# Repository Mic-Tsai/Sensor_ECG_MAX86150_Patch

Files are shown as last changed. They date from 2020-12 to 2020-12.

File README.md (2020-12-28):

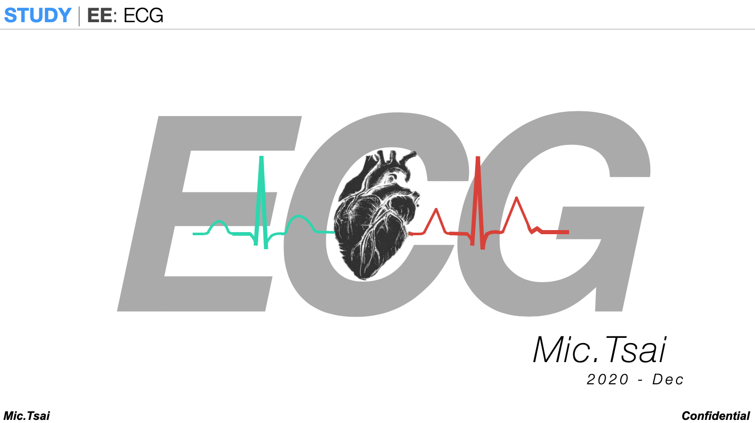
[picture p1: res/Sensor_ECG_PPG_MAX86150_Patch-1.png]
*Sensor_MAX86150*

# Sensor_ECG_PPG_MAX86150 | Patch



Arduino based sensor learning project. This project is further application from Health_Sensor_ecg_ppg_max86150 dev-board, plotting the ECG curve which used Processing on your computer.

 - Bias Cancellation | Store raw data in time, when new data coming that bias level will calculate as hysteresis filter.

 - Heart Rate Detect | Check windows will output the BPM results (ECG).

This board also support WiFi transmission via ESPNOW (ESP8266 Broadcast), and need power by battery. You need 2x esp8266 board.

1) Read receiver esp8266's mac address.
2) Fill it into the transmitter sketch. "ECG_ESP8266_MAX86150_V6"

** **A Known Issue** **

Sampling rate from MAX86150 set as 200sps, but ESP8266's multiplex with ESP-NOW and sensor hub reading task will low down the output sample rate to ~150sps. When you measuring your ECG in real-time plot may show the missing R-R interval. (R-peak missing!) Don't worry, it just the lower sample  caused.

```
Arduino tool kit, and require the following material:
- MCU: ESP8266 
- Sensor: MAX86150
```
##

For coding example, you need the following library:

* [protocentral_max86150_ecg_ppg](https://github.com/Protocentral/protocentral_max86150_ecg_ppg)

## 

Any question or need technical support:

* Contact me via mail (xbcke12345@gmail.com)

   

## 
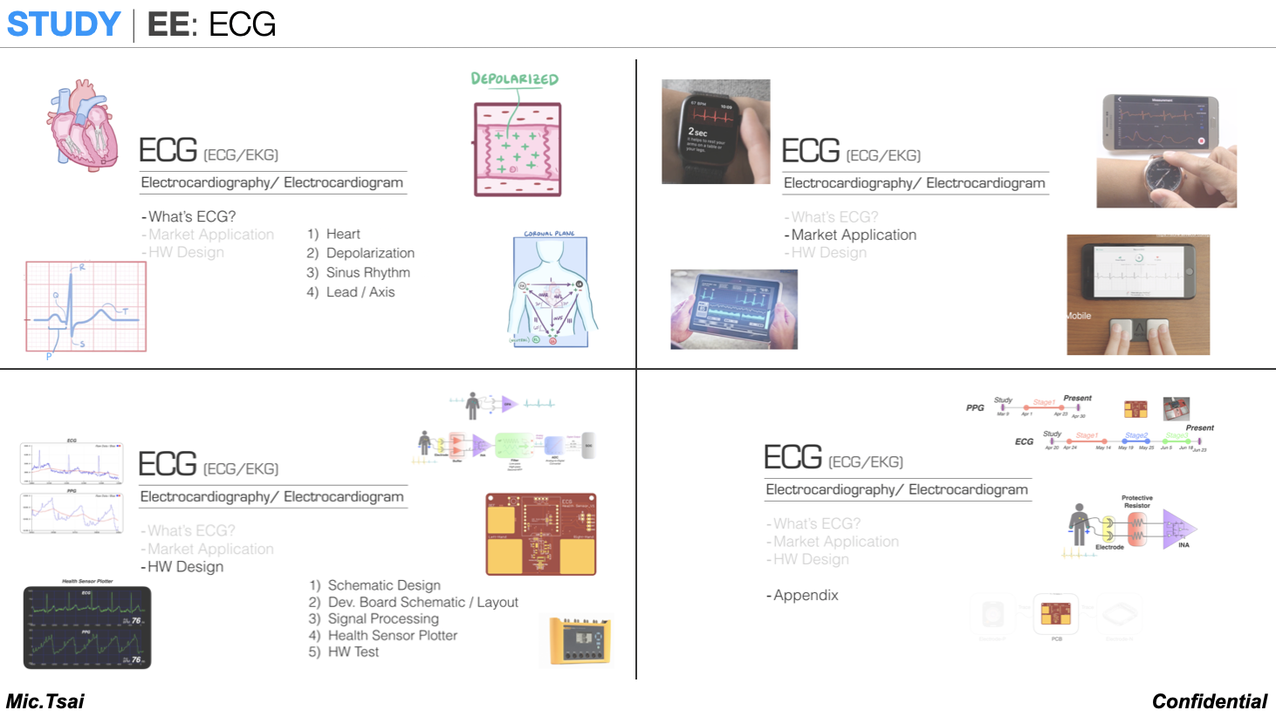
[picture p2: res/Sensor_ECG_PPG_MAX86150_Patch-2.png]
*Sensor_MAX86150*

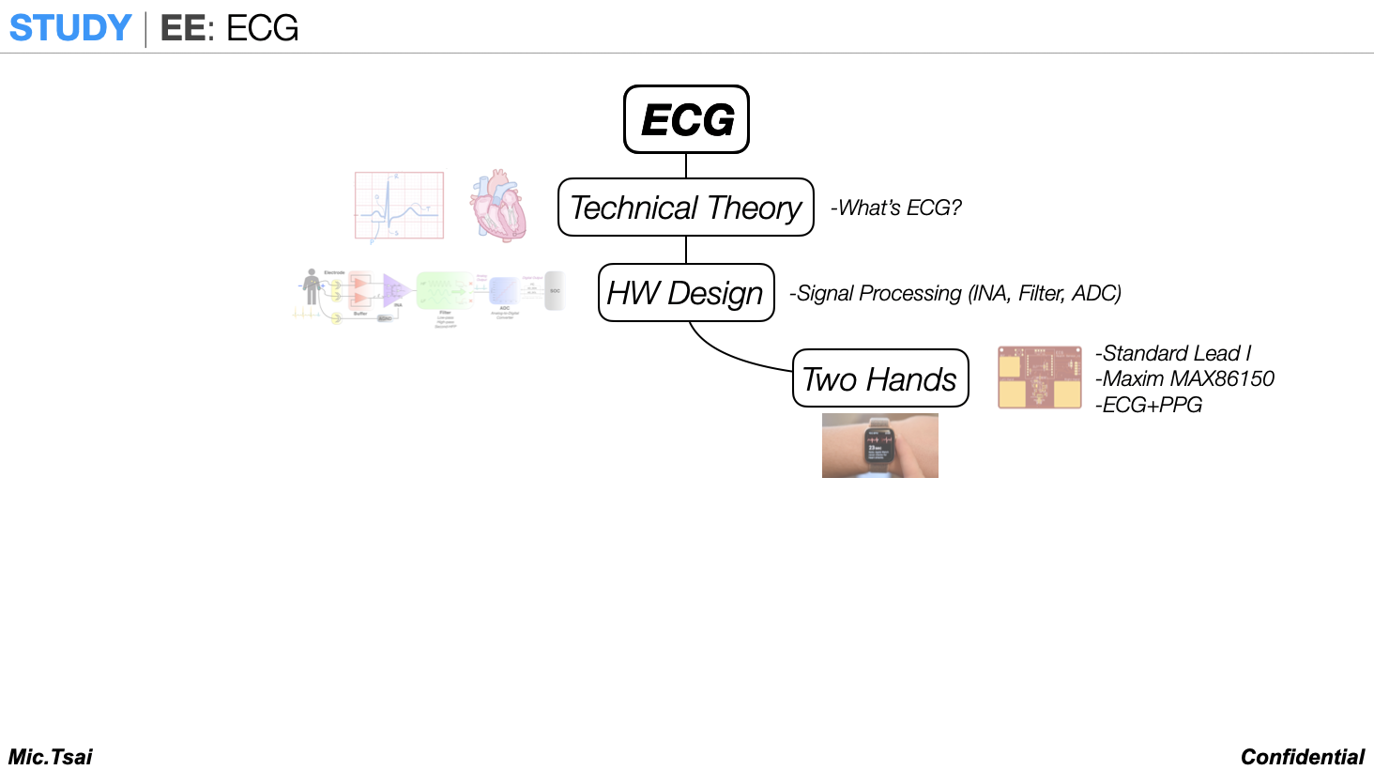
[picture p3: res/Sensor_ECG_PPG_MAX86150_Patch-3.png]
*Sensor_MAX86150*

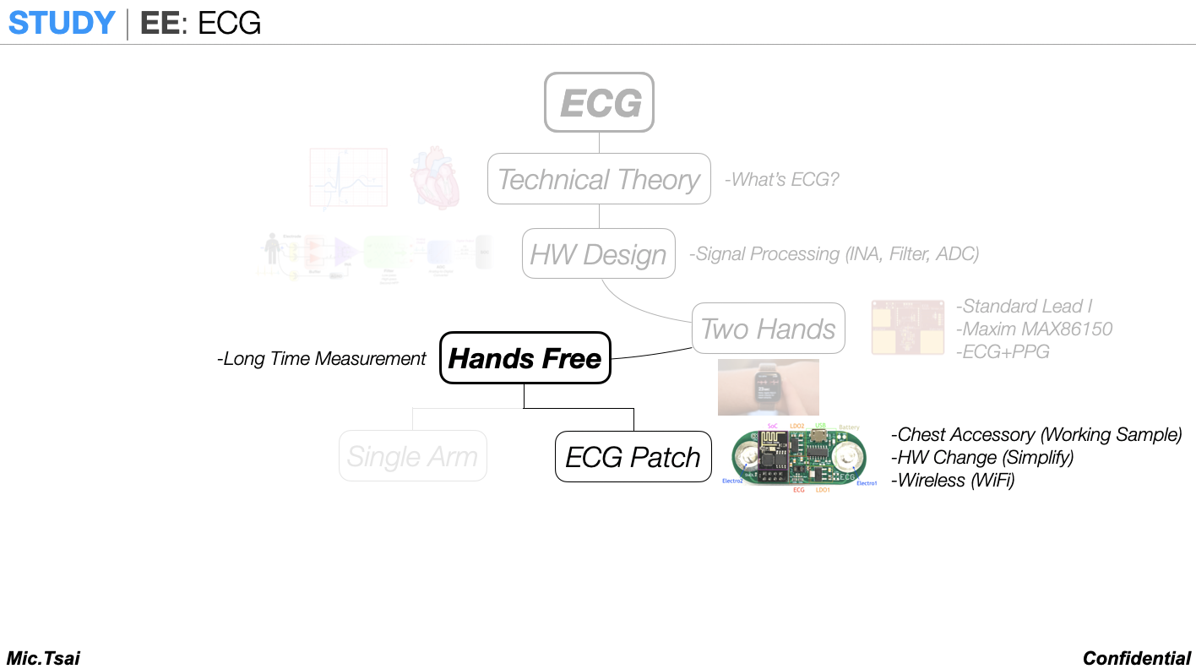
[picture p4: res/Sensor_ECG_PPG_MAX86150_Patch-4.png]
*Sensor_MAX86150*

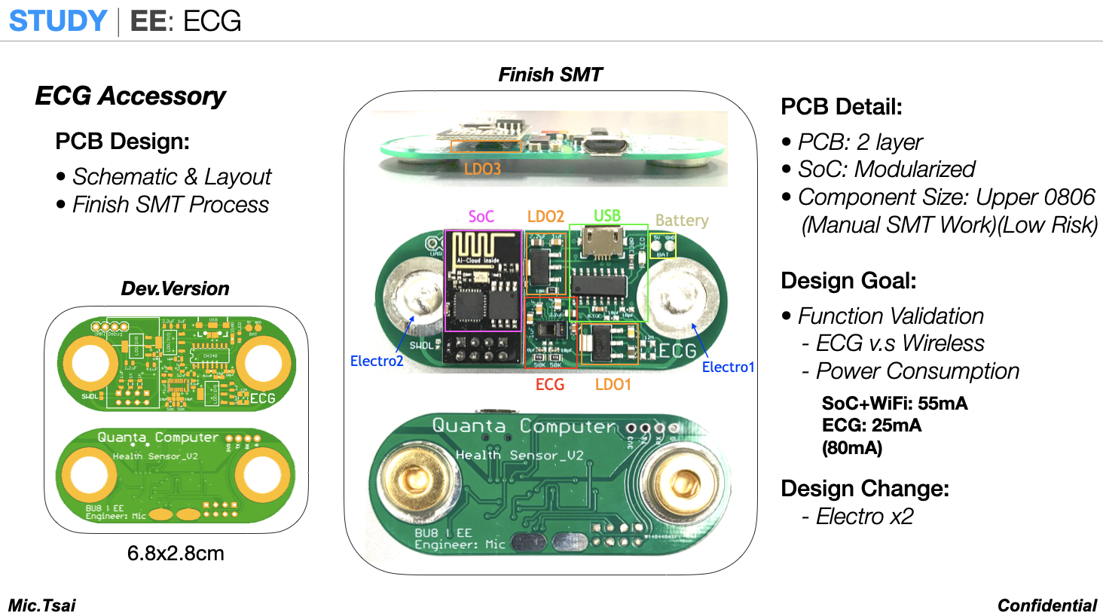
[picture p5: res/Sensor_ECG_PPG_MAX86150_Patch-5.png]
*Sensor_MAX86150*

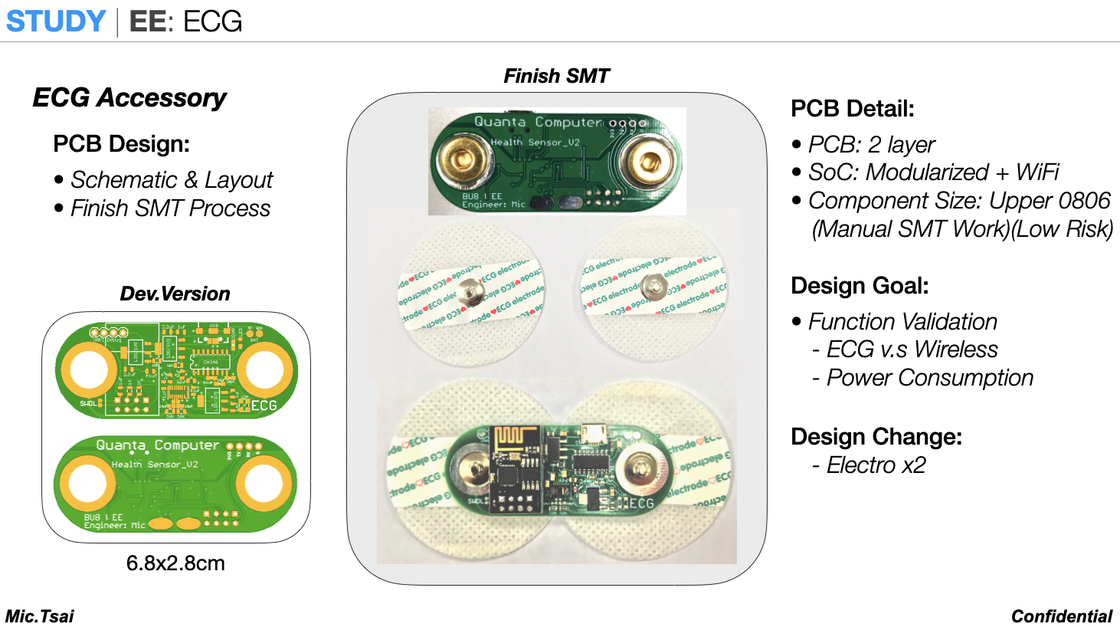
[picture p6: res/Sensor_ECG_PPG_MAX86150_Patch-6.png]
*Sensor_MAX86150*

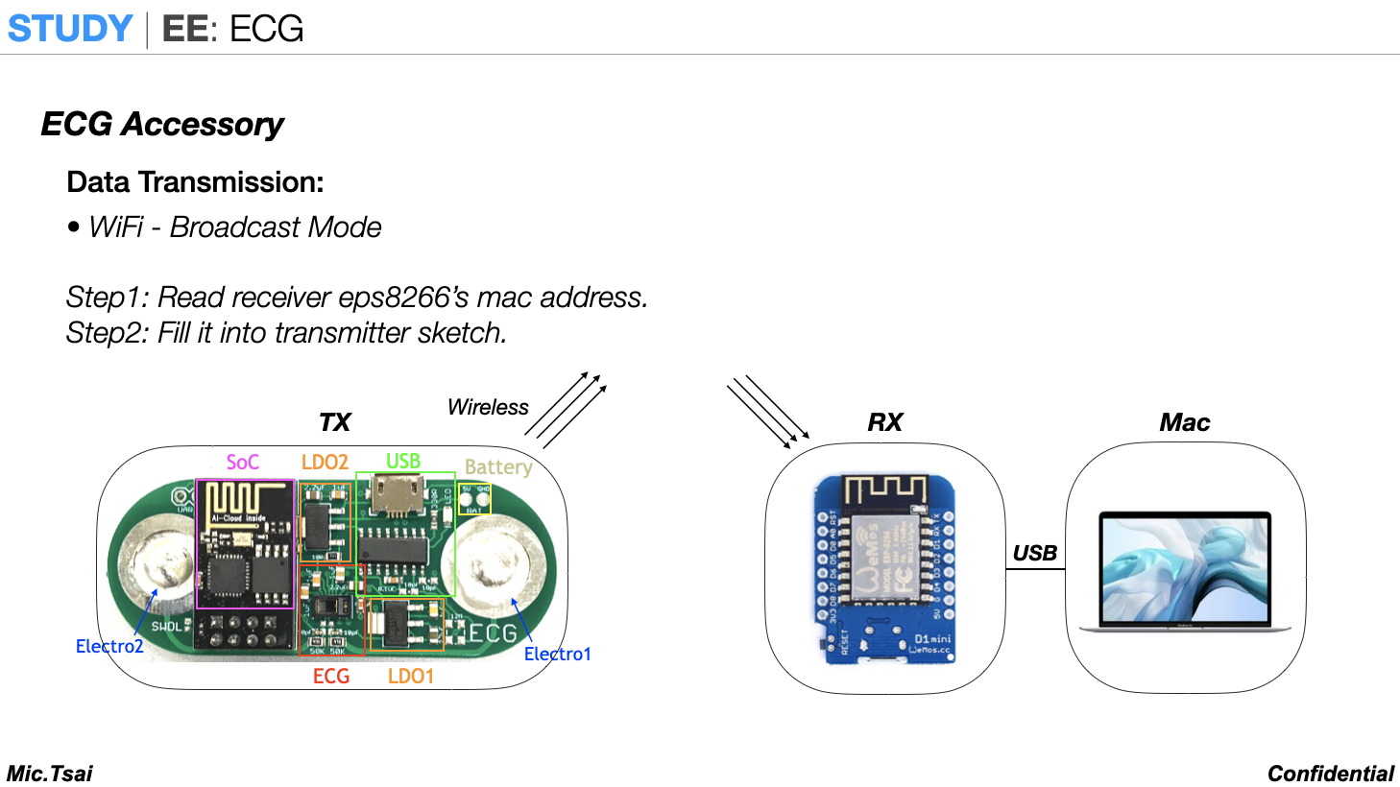
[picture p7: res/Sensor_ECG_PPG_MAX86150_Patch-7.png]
*Sensor_MAX86150*

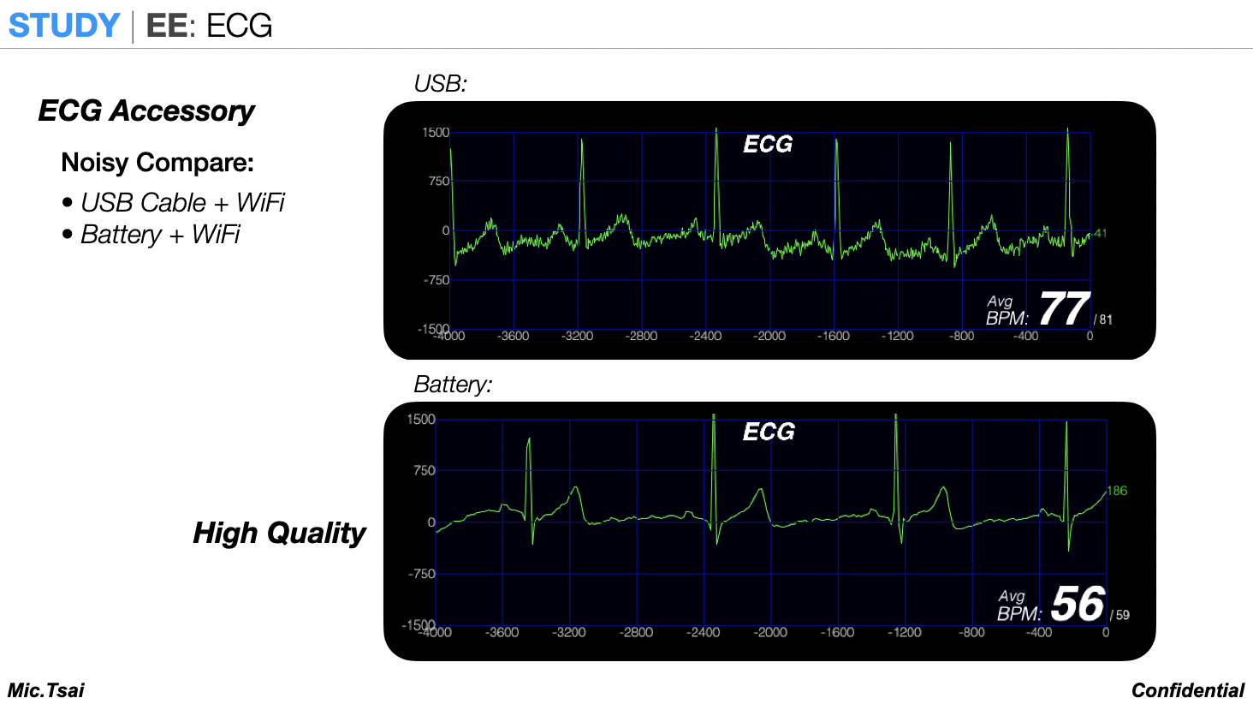
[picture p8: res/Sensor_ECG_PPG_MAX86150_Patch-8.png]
*Sensor_MAX86150*

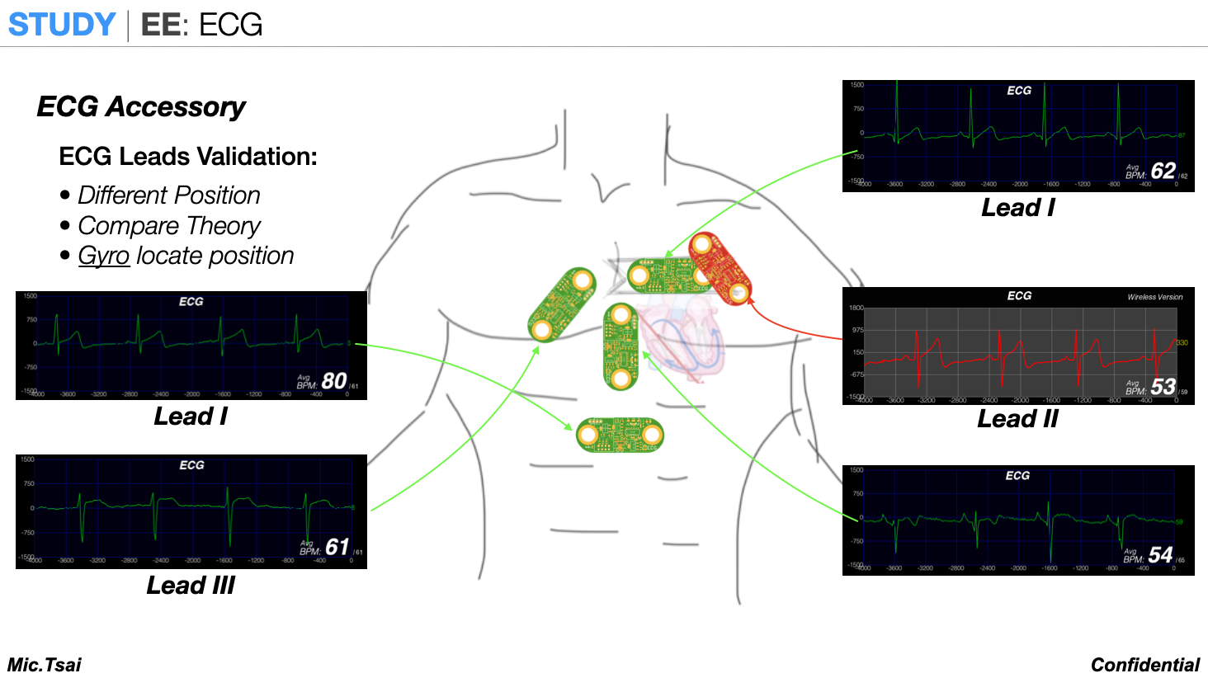
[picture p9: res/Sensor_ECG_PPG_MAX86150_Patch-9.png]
*Sensor_MAX86150*

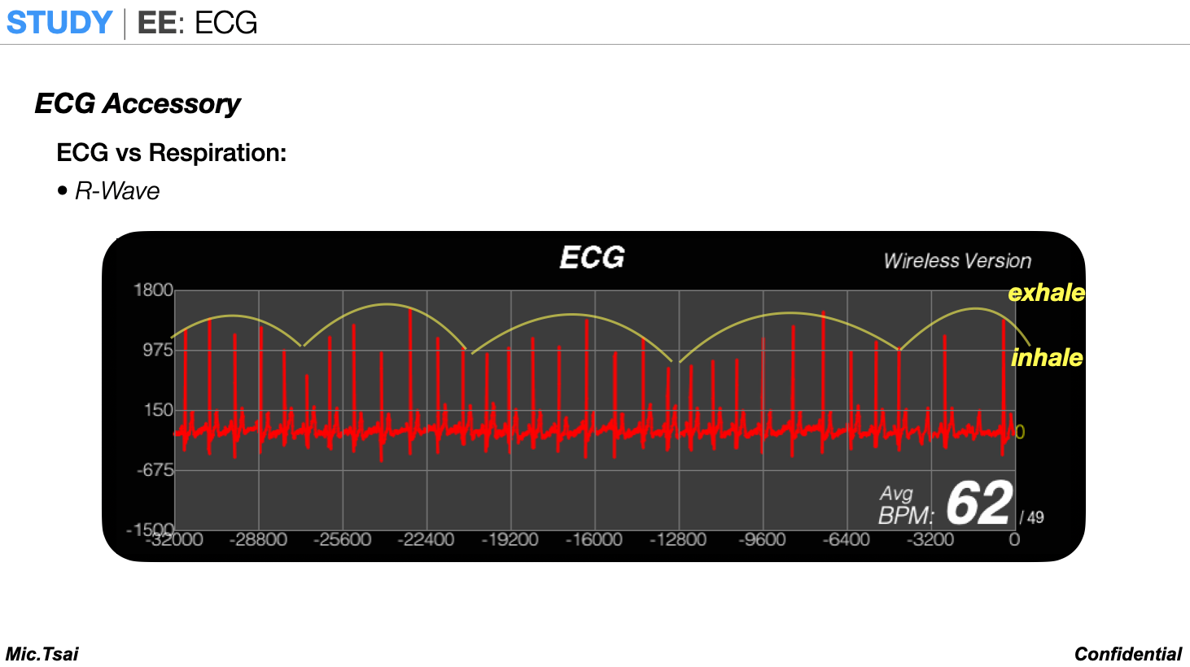
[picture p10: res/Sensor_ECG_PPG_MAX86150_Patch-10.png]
*Sensor_MAX86150*

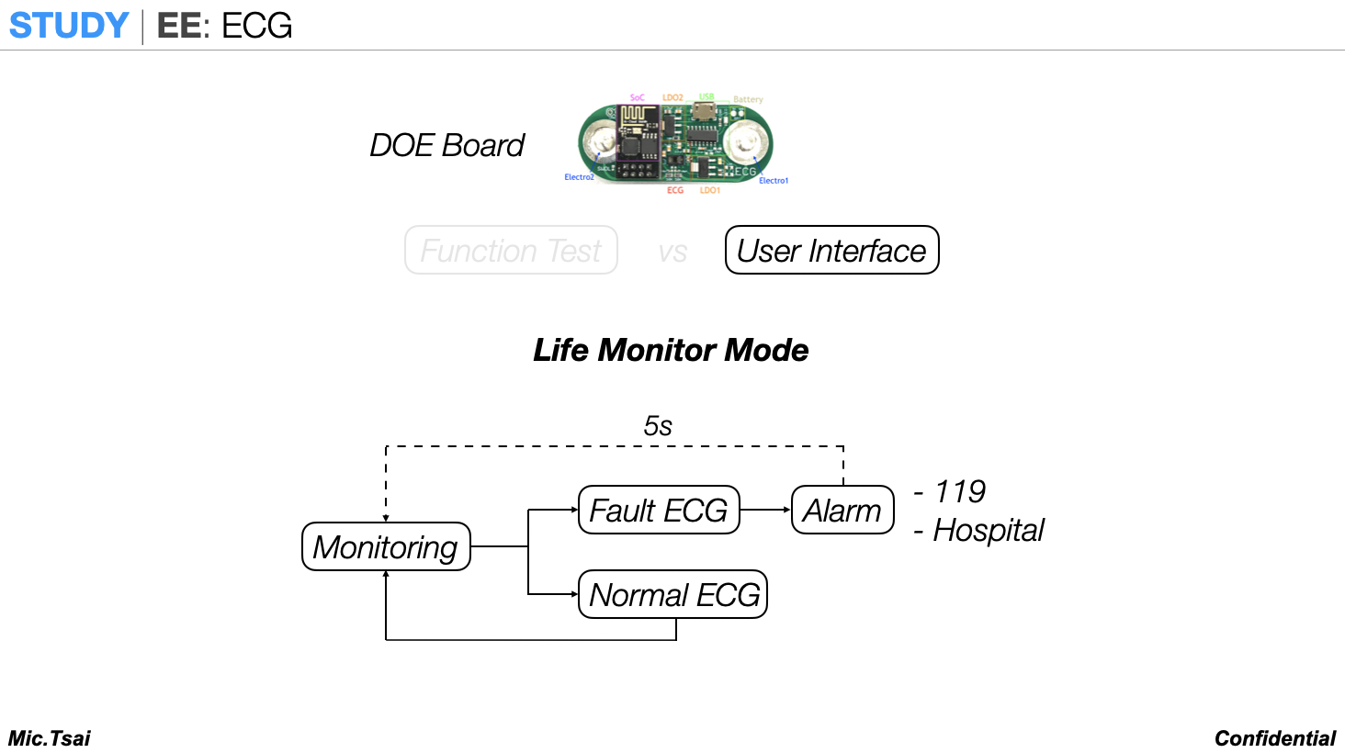
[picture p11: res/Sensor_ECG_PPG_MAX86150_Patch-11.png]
*Sensor_MAX86150*

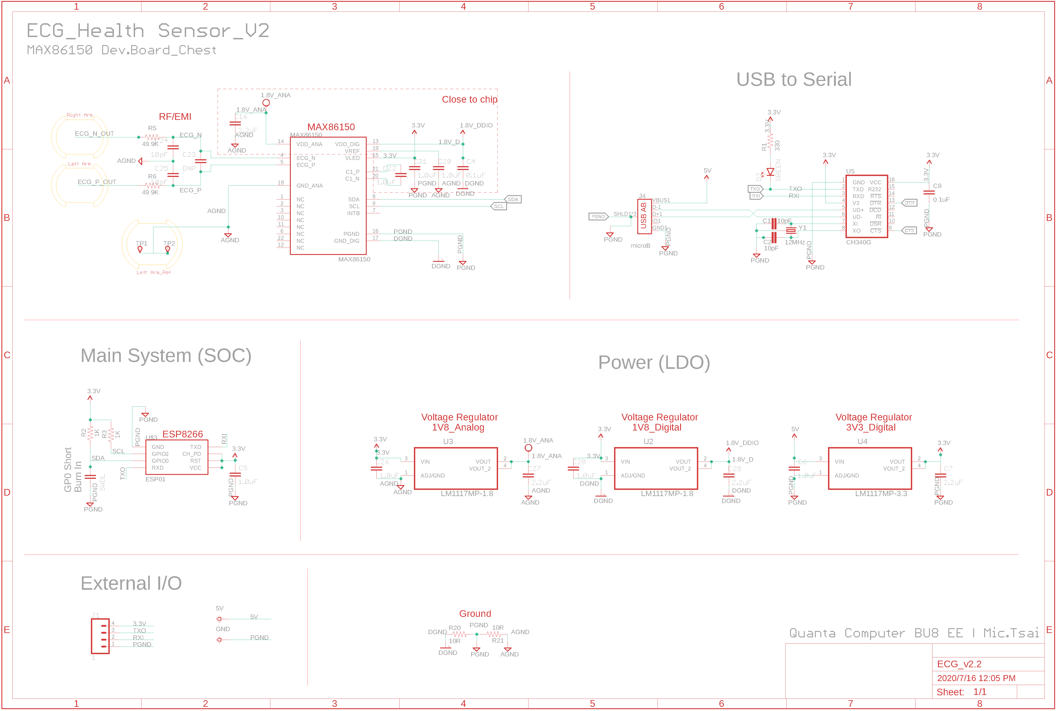
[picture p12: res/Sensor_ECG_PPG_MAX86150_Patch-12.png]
*Sensor_MAX86150*

## 

>### License Information
>>This product is open source! Both, our hardware and software are open source and licensed under the following:
>>#### Hardware
>>>All hardware is released under [Creative Commons Share-alike 4.0 International](http://creativecommons.org/licenses/by-sa/4.0/)
>>#### Software 
>>>All software is released under the MIT License [http://opensource.org/licenses/MIT](http://opensource.org/licenses/MIT)
>>#### Documentation
>>>The documentation on this page is released under [Creative Commons Share-alike 4.0 International](http://creativecommons.org/licenses/by-sa/4.0/)

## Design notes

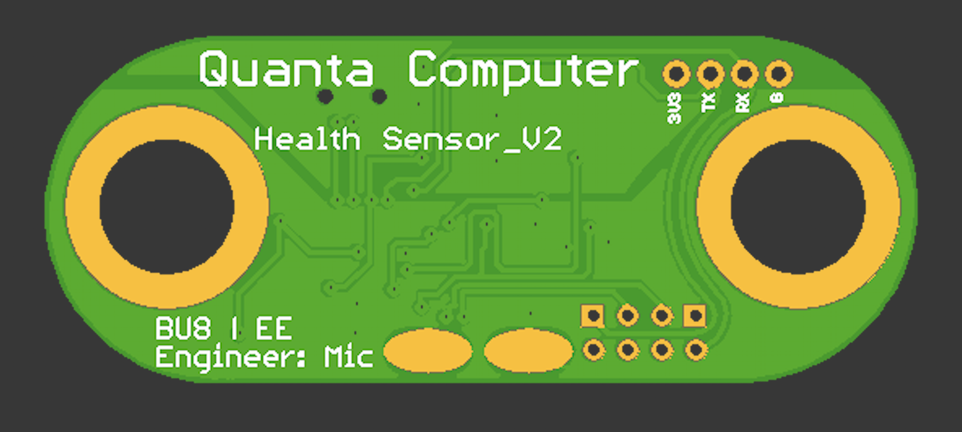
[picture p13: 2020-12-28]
hardware/ECG_max86150_patch_v2.2/ECG_max86150_patch_v2.2_B.png

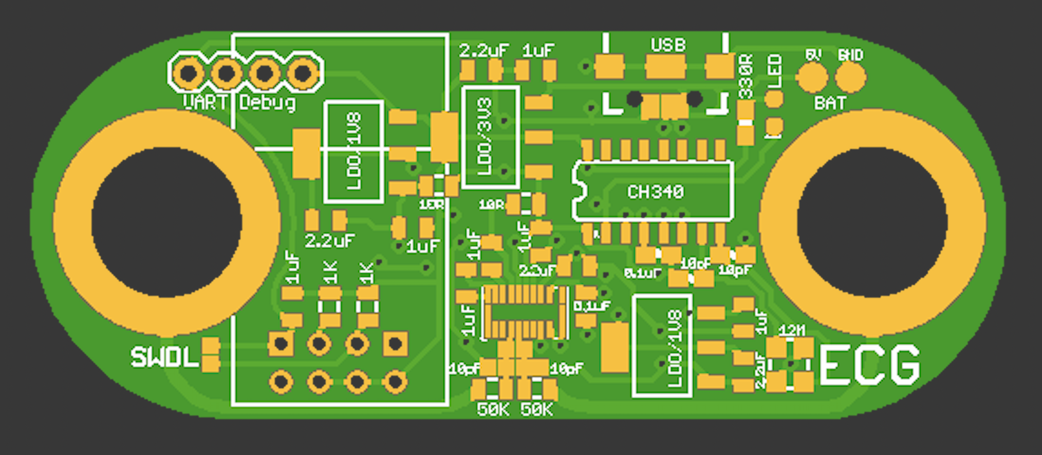
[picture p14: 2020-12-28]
hardware/ECG_max86150_patch_v2.2/ECG_max86150_patch_v2.2_T.png

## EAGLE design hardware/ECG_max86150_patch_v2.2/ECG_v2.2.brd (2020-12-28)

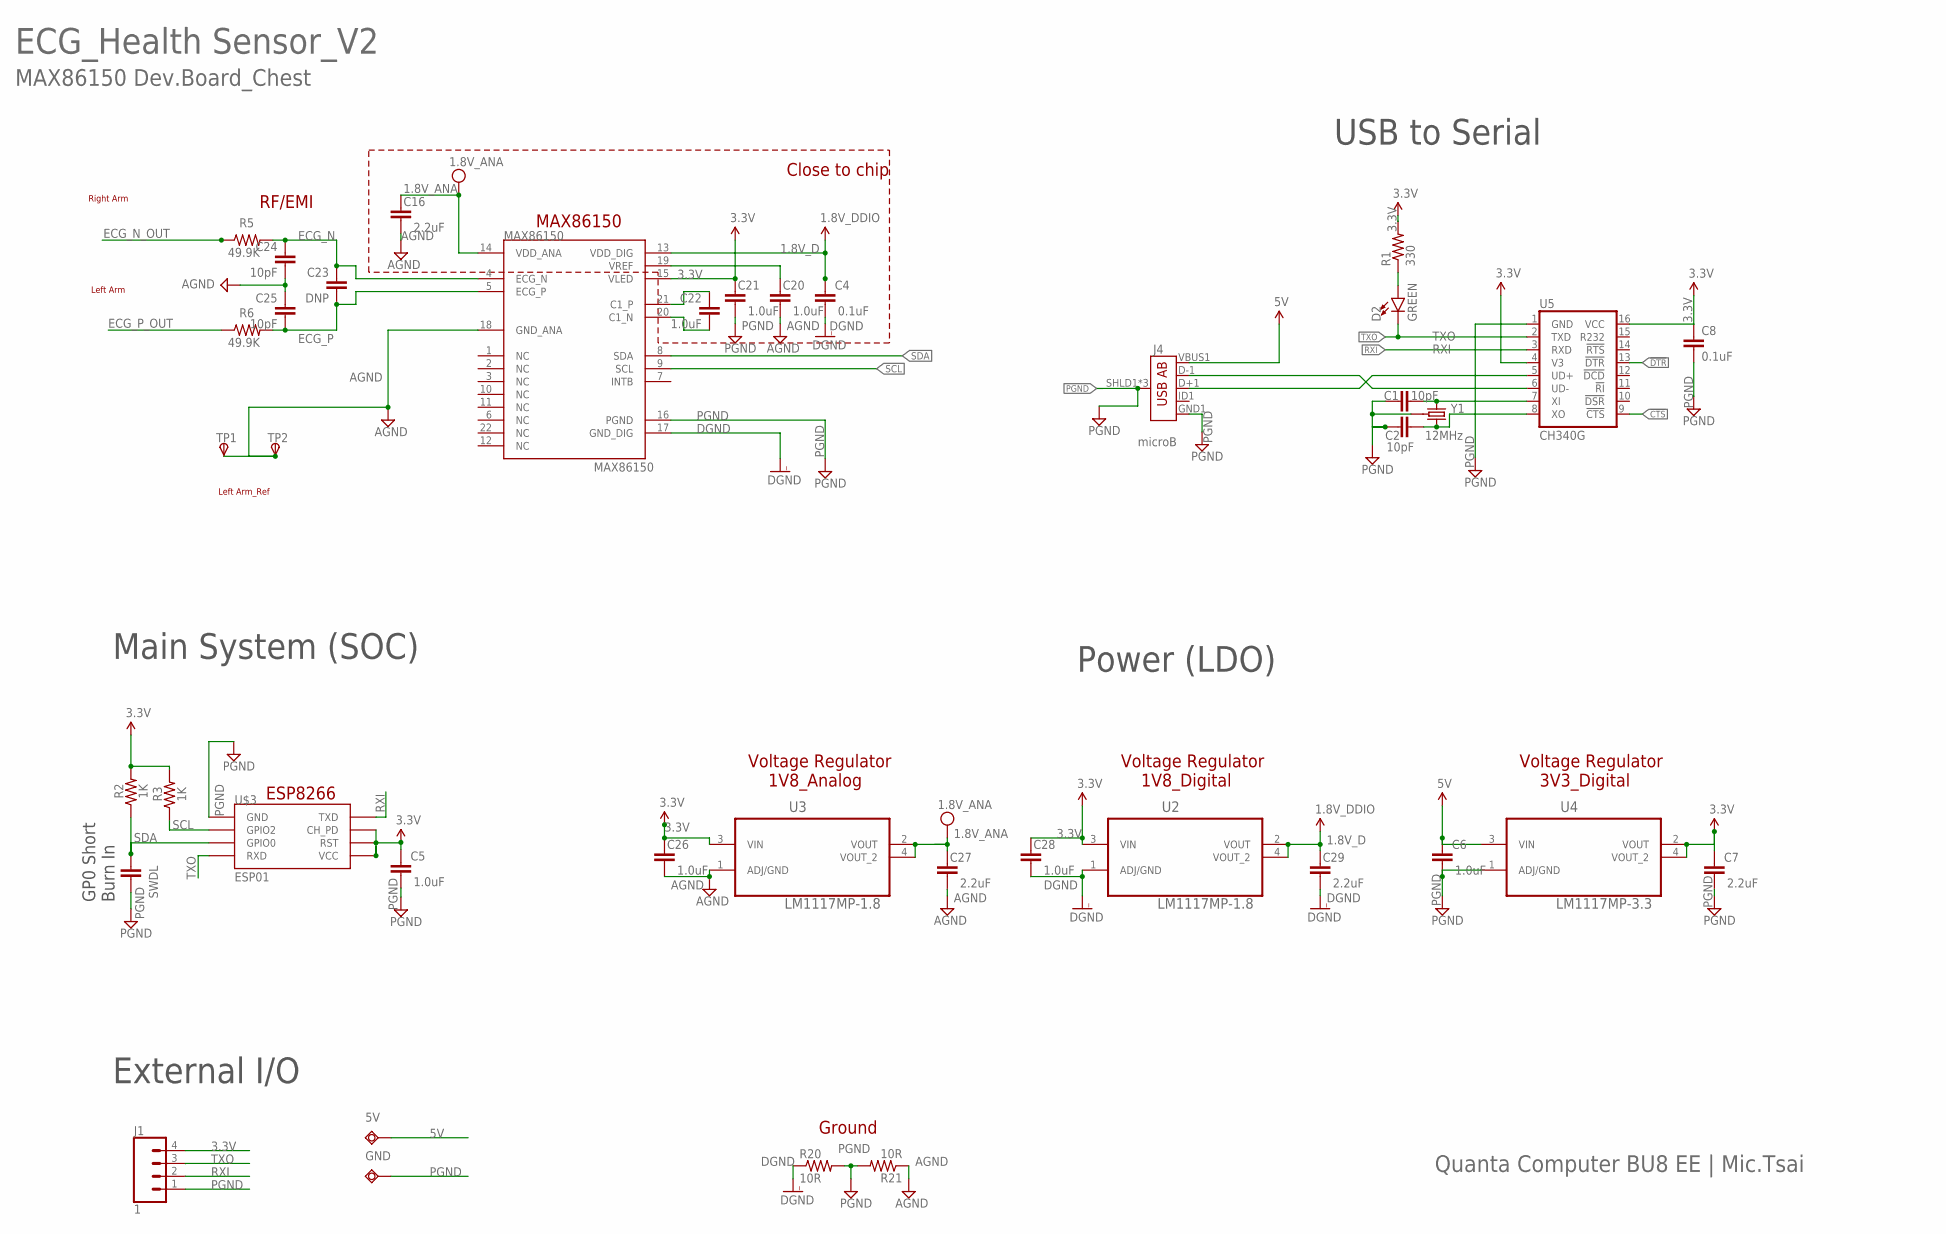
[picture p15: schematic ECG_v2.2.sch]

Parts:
5V: TPSQTP20R; TP20R
C1, C2: 10pF; 0603-CAP
C4: 0.1uF; 0805
C5, C6, C20, C21, C22, C26, C28: 1.0uF; 0805
C7, C16, C27, C29: 2.2uF; 0805
C8: 0.1uF; 0603-CAP
C23: DNP; 0402
C24, C25: 10pF; 0402
D2: GREEN; LED-0603
GND: TPSQTP20R; TP20R
J1: 1; 1X04
J4: microB; USB-AB-MICRO-SMD
MAX86150: MAX86150
R1: 330; 0603-RES
R2, R3: 1K; 0805
R5, R6: 49.9K; 0805
R20, R21: 10R; 0805
SWDL: 10pF; 0402
TP1, TP2: TPSB1,27; B1,27
U2, U3: LM1117MP-1.8; SOT230P696X180-4N
U4: LM1117MP-3.3; SOT230P696X180-4N
U5: CH340G; SO016
U$3: ESP01
Y1: 12MHz; CRYSTAL-SMD-3.2X2.5

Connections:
1.8V_ANA: C16.1, C27.1, MAX86150.14 (VDD_ANA), U3.2 (VOUT), U3.4 (VOUT_2)
1.8V_D: C4.1, C29.1, MAX86150.13 (VDD_DIG), U2.2 (VOUT), U2.4 (VOUT_2)
3.3V: C5.1, C7.1, C8.1, C21.1, C26.1, C28.1, J1.4, MAX86150.15 (VLED), R1.2, R2.2, R3.2, U2.3 (VIN), U3.3 (VIN), U4.2 (VOUT), U4.4 (VOUT_2), U5.4 (V3), U5.16 (VCC), U$3.CH_PD, U$3.RST, U$3.VCC
5V: 5V.TP, C6.1, J4.VBUS1 (VBUS), U4.3 (VIN)
!CTS: U5.9 (!CTS)
!DTR: U5.13 (!DTR)
AGND: C16.2, C20.2, C24.2, C25.1, C26.2, C27.2, MAX86150.18 (GND_ANA), R21.1, TP1.PP, TP2.PP, U3.1 (ADJ/GND)
DGND: C4.2, C28.2, C29.2, MAX86150.17 (GND_DIG), R20.1, U2.1 (ADJ/GND)
ECG_N: C23.1, C24.1, MAX86150.4 (ECG_N), R5.2
ECG_N_OUT: R5.1
ECG_P: C23.2, C25.2, MAX86150.5 (ECG_P), R6.2
ECG_P_OUT: R6.1
unnamed: D2.A, R1.1
unnamed: C22.1, MAX86150.21 (C1_P)
unnamed: C22.2, MAX86150.20 (C1_N)
unnamed: C20.1, MAX86150.19 (VREF)
unnamed: C2.2, U5.8 (XO), Y1.3 (2)
unnamed: C1.2, U5.7 (XI), Y1.1
unnamed: J4.D-1 (D-), U5.6 (UD-)
unnamed: J4.D+1 (D+), U5.5 (UD+)
PGND: C1.1, C2.1, C5.2, C6.2, C7.2, C8.2, C21.2, GND.TP, J1.1, J4.GND1 (GND), J4.SHLD1 (SHIELD), J4.SHLD2 (SHIELD), J4.SHLD3 (SHIELD), MAX86150.16 (PGND), R20.2, R21.2, SWDL.2, U4.1 (ADJ/GND), U5.1 (GND), U$3.GND, Y1.2 (GND), Y1.4 (GND)
RXI: J1.2, U5.3 (RXD), U$3.TX (TXD)
SCL: MAX86150.9 (SCL), R3.1, U$3.GPIO2
SDA: MAX86150.8 (SDA), R2.1, SWDL.1, U$3.GPIO0
TXO: D2.C, J1.3, U5.2 (TXD), U$3.RX (RXD)

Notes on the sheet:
Close to chip
ECG_Health Sensor_V2
MAX86150 Dev.Board_Chest
Quanta Computer BU8 EE | Mic.Tsai
Left Arm
RF/EMI
Ground
Right Arm
Left Arm_Ref
Voltage Regulator 1V8_Analog
Voltage Regulator 1V8_Digital
MAX86150
ESP8266
USB to Serial
GP0 Short Burn In
Voltage Regulator 3V3_Digital
Main System (SOC)
Power (LDO)
External I/O

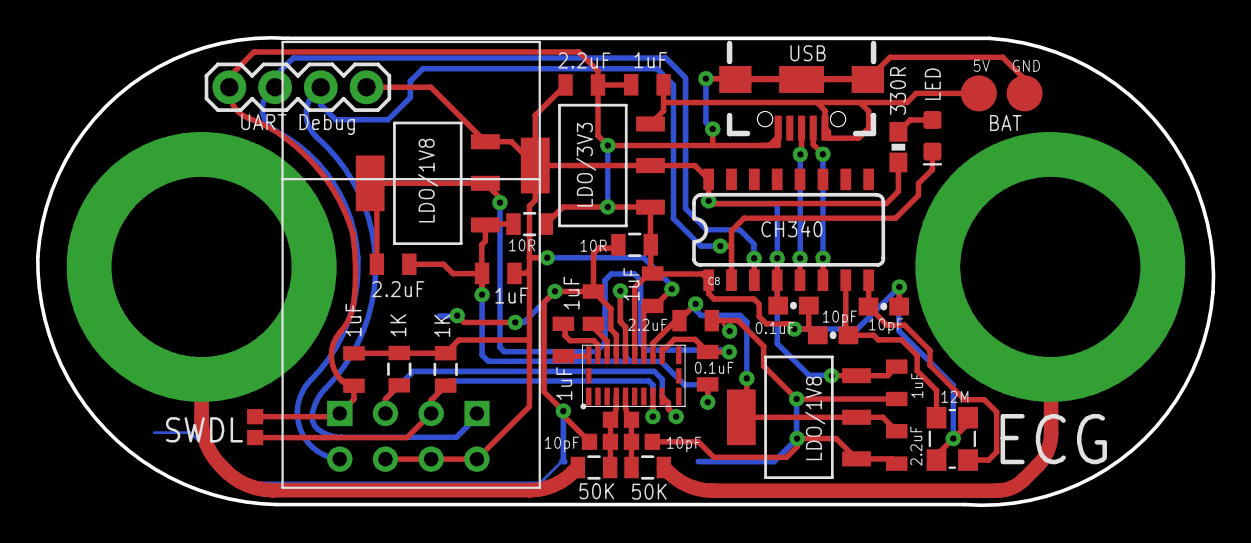
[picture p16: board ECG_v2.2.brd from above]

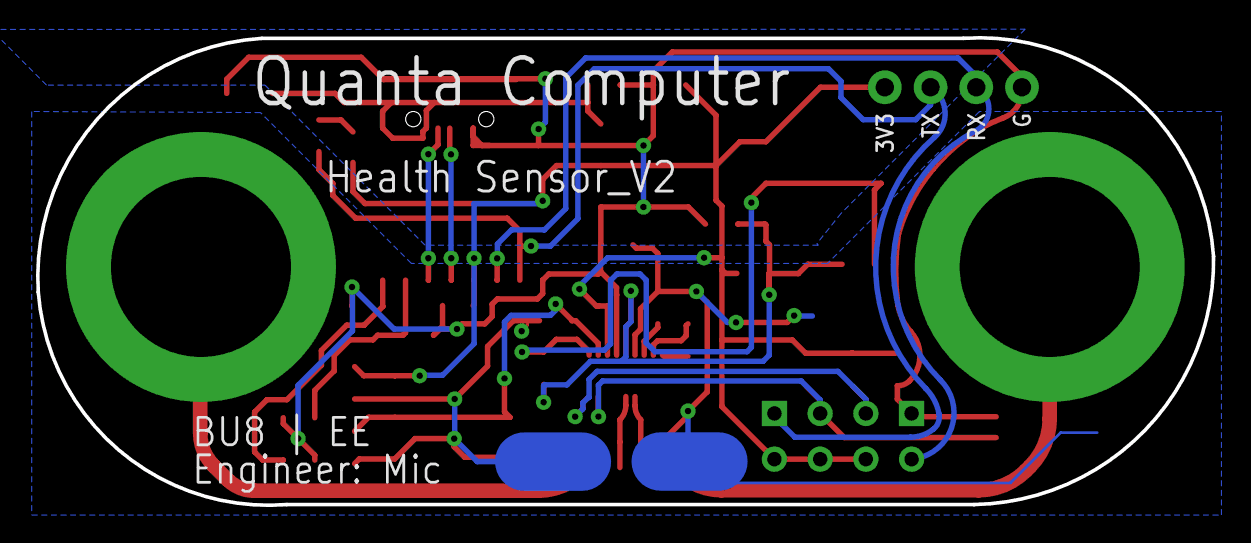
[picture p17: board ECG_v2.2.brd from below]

Board: 2 copper layers, 65.3 x 26.0 mm, 40 parts (2 on the bottom side), 21 nets.

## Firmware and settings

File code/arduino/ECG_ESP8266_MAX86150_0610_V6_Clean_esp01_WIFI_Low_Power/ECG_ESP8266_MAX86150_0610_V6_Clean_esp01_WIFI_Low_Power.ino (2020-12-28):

// ###################################################################################
// # Project: ECG Health Sensor
// # Engineer:  Mic.Tsai
// # Date:  31 July 2020
// # Objective: Dev.board
// # Usage: ESP8266
// # Modified: Mode Select with filter and PPG
// ###################################################################################

// ########################
#include <ESP8266WiFi.h>
#include <espnow.h>
// ########################

#include <Wire.h>
#include "max86150.h"

byte TestledBrightness = 1; //Options: 0=Off to 255=50mA //0x1F

// # ECG sensor
int16_t ecgsigned16;
int16_t redunsigned16;
uint16_t ppgunsigned16;

MAX86150 max86150Sensor;

int Filter_Value;
int Filter_Value2;
int Value;
int Value2;

// ########################


// REPLACE WITH RECEIVER MAC Address
uint8_t broadcastAddress[] = {0xF4, 0xCF, 0xA2, 0x6D, 0x3B, 0xA1};
//uint8_t broadcastAddress[] = {0x5C, 0xCF, 0x7F, 0xB9, 0x8A, 0x6A};
// uint8_t broadcastAddress[] = {0xF4, 0xCF, 0xA2, 0x6D, 0x2E, 0xDF};
// uint8_t broadcastAddress[] = {0xFF, 0xFF, 0xFF, 0xFF, 0xFF, 0xFF};

// Structure example to send data
// Must match the receiver structure
typedef struct struct_message {
  int a;
  int b;
  int c;
  int d;
/*
  char a[32];
  int b;
  float c;
  String d;
  bool e;
*/
  
} struct_message;

// Create a struct_message called myData
struct_message myData;

unsigned long lastTime = 0;  
unsigned long timerDelay = 1;  // send readings timer

// Callback when data is sent
void OnDataSent(uint8_t *mac_addr, uint8_t sendStatus) {
  Serial.print("Last Packet Send Status: ");
  if (sendStatus == 0){
    Serial.println("Delivery success");
  }
  else{
    Serial.println("Delivery fail");
  }
}

// ########################

void setup()
{

//~~~~~~~~~~~~~~~~~~~~~~~~~~~
    Wire.begin(0, 2); /* join i2c bus with SDA=D1 and SCL=D2 of NodeMCU *////
//~~~~~~~~~~~~~~~~~~~~~~~~~~~
    Serial.begin(38400);

//~~~~~~~~~~~~~~~~~~~~~~~~~~~
    WiFi.mode( WIFI_OFF );
    WiFi.forceSleepBegin();
    Serial.println("WiFi is down");
//~~~~~~~~~~~~~~~~~~~~~~~~~~~

    Serial.println("MAX86150 Basic Readings Example");

    // Initialize sensor
    if (max86150Sensor.begin(Wire, I2C_SPEED_FAST) == false)
    {
        Serial.println("MAX86150 was not found. Please check wiring/power. ");
        while (1);
    }

    //Setup to sense a nice looking saw tooth on the plotter
    byte ledBrightness = 0; //Options: 0=Off to 255=50mA
    byte sampleAverage = 1; //Options: 1, 2, 4, 8, 16, 32
    byte ledMode = 1; //Options: 1 = Red only, 2 = Red + IR, 3 = Red + IR + Green
    int sampleRate = 50; //Options: 50, 100, 200, 400, 800, 1000, 1600, 3200
    int pulseWidth = 69; //Options: 69, 118, 215, 411
    int adcRange = 2048; //Options: 2048, 4096, 8192, 16384
  
    max86150Sensor.setup(ledBrightness, sampleAverage, ledMode, sampleRate, pulseWidth, adcRange); //Configure sensor with these settings
//    max86150Sensor.writeRegister8(0x5E,0x11,0x00);
//    max86150Sensor.writeRegister8(0x5E,0x12,0x00);


// ########################

  // Set device as a Wi-Fi Station
  WiFi.mode(WIFI_STA);

  // Init ESP-NOW
  if (esp_now_init() != 0) {
    Serial.println("Error initializing ESP-NOW");
    return;
  }

  // Once ESPNow is successfully Init, we will register for Send CB to
  // get the status of Trasnmitted packet
  esp_now_set_self_role(ESP_NOW_ROLE_CONTROLLER);
  esp_now_register_send_cb(OnDataSent);
  
  // Register peer
  esp_now_add_peer(broadcastAddress, ESP_NOW_ROLE_SLAVE, 1, NULL, 0);

// ########################


}

void loop()
{
  
    ecgsigned16 = (int16_t) (max86150Sensor.getECG()>>1);
 //   ecgsigned16 = (int16_t) (max86150Sensor.getECG()>>2);
    Filter_Value = Filter();


// ########################

    // Set values to send
    myData.a = ecgsigned16;
    myData.b = Filter_Value;    
    
    // Send message via ESP-NOW
    esp_now_send(broadcastAddress, (uint8_t *) &myData, sizeof(myData));
  
// ########################


    Serial.print(millis());
    Serial.print(",");
    Serial.print(ecgsigned16 - Filter_Value);
    Serial.print(",");
    Serial.print(ppgunsigned16 - Filter_Value2);
    Serial.println(",");

}
//>>>>>>>>>>>>>>>>>>>>>>>>>>>>>>>>>>>>>>>>>>>>>>
//>>>>>>>>>>>>>>>>>>>>>>>>>>>>>>>>>>>>>>>>>>>>>>

//>>>>>>>>>>>>>>>>>>>>>>>>>>>>>>>>>>>>>>>>>>>>>>>>>>>>>>>>>>>>>>>>>>>>>>
//>>>>>>>>>>>>>>>>>>>>>>>>>>> Get ECG Data >>>>>>>>>>>>>>>>>>>>>>>>>>>>>
//>>>>>>>>>>>>>>>>>>>>>>>>>>>>>>>>>>>>>>>>>>>>>>>>>>>>>>>>>>>>>>>>>>>>>>
void ECG()
{ 
      ecgsigned16 = (int16_t) (max86150Sensor.getECG()>>2);
}
//>>>>>>>>>>>>>>>>>>>>>>>>>>>>>>>>>>>>>>>>>>>>>>>>>>>>>>>>>>>>>>>>>>>>>>
//>>>>>>>>>>>>>>>>>>>>>>>>>>> Get ECG Data >>>>>>>>>>>>>>>>>>>>>>>>>>>>>
//>>>>>>>>>>>>>>>>>>>>>>>>>>>>>>>>>>>>>>>>>>>>>>>>>>>>>>>>>>>>>>>>>>>>>>


//>>>>>>>>>>>>>>>>>>>>>>>>>>>>>>>>>>>>>>>>>>>>>>>>>>>>>>>>>>>>>>>>>>>>>>
//>>>>>>>>>>>>>>>>>>>>>>>>>>> Get PPG Data >>>>>>>>>>>>>>>>>>>>>>>>>>>>>
//>>>>>>>>>>>>>>>>>>>>>>>>>>>>>>>>>>>>>>>>>>>>>>>>>>>>>>>>>>>>>>>>>>>>>>
void PPG()
{ 
     ppgunsigned16 = (uint16_t) (max86150Sensor.getFIFORed()>>2);
}
//>>>>>>>>>>>>>>>>>>>>>>>>>>>>>>>>>>>>>>>>>>>>>>>>>>>>>>>>>>>>>>>>>>>>>>
//>>>>>>>>>>>>>>>>>>>>>>>>>>> Get PPG Data >>>>>>>>>>>>>>>>>>>>>>>>>>>>>
//>>>>>>>>>>>>>>>>>>>>>>>>>>>>>>>>>>>>>>>>>>>>>>>>>>>>>>>>>>>>>>>>>>>>>>
void ECGFilter()
{ 
    Filter_Value = Filter();
    Serial.println(ecgsigned16 - Filter_Value); 
}
//>>>>>>>>>>>>>>>>>>>>>>>>>>>>>>>>>>>>>>>>>>>>>>>>>>>>>>>>>>>>>>>>>>>>>>
//>>>>>>>>>>>>>>>>>>>>>>>>>>>>>>>>>>>>>>>>>>>>>>>>>>>>>>>>>>>>>>>>>>>>>>

// ecg data in
int Get_AD() {
  return ecgsigned16;
}

// 一階滯後濾波法
#define FILTER_A 0.01
int Filter() {
  int NewValue;
  NewValue = Get_AD();
  Value = (int)((float)NewValue * FILTER_A + (1.0 - FILTER_A) * (float)Value);
  return Value;
}

//>>>>>>>>>>>>>>>>>>>>>>>>>>>> PPG  >>>>>>>>>>>>>>>>>>>>>>>>>>>>>>>>>>>>

// ecg data in
int Get_AD2() {
  return ppgunsigned16;
}

// 一階滯後濾波法
#define FILTER_A2 0.01
int Filter2() {
  int NewValue2;
  NewValue2 = Get_AD2();
  Value2 = (int)((float)NewValue2 * FILTER_A2 + (1.0 - FILTER_A2) * (float)Value2);
  return Value2;
}

//>>>>>>>>>>>>>>>>>>>>>>>>>>>>>>>>>>>>>>>>>>>>>>>>>>>>>>>>>>>>>>>>>>>>>>
//>>>>>>>>>>>>>>>>>>>>>>>>>>>>>>>>>>>>>>>>>>>>>>>>>>>>>>>>>>>>>>>>>>>>>>

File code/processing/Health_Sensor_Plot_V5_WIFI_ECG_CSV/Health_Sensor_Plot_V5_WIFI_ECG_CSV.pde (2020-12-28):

// Base on ArduinoScope 
// ###################################################################################
// # Project: ECG Health Sensor Plots
// # Engineer:  Mic.Tsai
// # Date:  10 June 2020
// # Objective: Dev.board
// # Usage: ESP8266
// # Modified: Mode Select with filter and PPG
// ###################################################################################
import java.io.BufferedWriter;
import java.io.FileWriter;
String outFilename = "/Users/mic/Desktop/ECG_Data.csv";

import processing.sound.*;
//create a variable of type SoundFile
SoundFile mySoundFile;

long lastTime = 0;  
long timerDelay = 4000;  // send readings timer

long lastTimeecg = 0;  
long timerDelayecg = 4000;  // send readings timer

import processing.serial.*;
Serial ArduinoPort;  // Create object from Serial class
  
int NumOfScopes,NumOfInput=2;
int data_span=10000;
Strage dfs = new Strage();
Scope[] sp;
 
int fontsize=16;
PFont myFont;
PFont myFont2;
PFont myFont3;
 
//============================= # ECG BPM calculate 
int LastTimeECG=0;
int ThisTimeECG; 
float inByteECG = 0;
int BPMECG = 0;
int beat_oldECG = 0;
float[] beatsECG = new float[500];  // Used to calculate average BPM
int averagebuffervalueecg=5;
int beatIndexECG;
boolean belowThresholdECG = true; 

int valssECG;
int timestampAllECG;
 
boolean BPMTimingECG=false;
boolean BeatCompleteECG=false;

float beatsPerMinuteECG;
int beatAvgECG;
int averageECG = 0;
int averageECG2 = 0;
 
boolean Alert = false;

//============================= # ECG BPM calculate 

//============================= # PPG BPM calculate 
int LastTime=0;
int ThisTime; 
float inByte = 0;
int BPM = 0;
int beat_old = 0;
float[] beats = new float[500];  // Used to calculate average BPM
int averagebuffervalueppg=5;
int beatIndex;
boolean belowThreshold = true; 

int valssPPG;
int timestampAll;
 
boolean BPMTiming=false;
boolean BeatComplete=false;

float beatsPerMinute;
int beatAvg;
int averageppg = 0;

//============================= # PPG BPM calculate 

//>>>>>>>>>>>>>>>>>>>>>>>>>>>>>>>>>>>>>>>>>>>>>>>>>>>>>>>>>>>>>>>>>>>>>>>>>>>>>>>>>>Set ECG Limit>>>>>>>
// # ECG limit
float UpperThresholdECG = 500  ;
float LowerThresholdECG = 0  ;
//>>>>>>>>>>>>>>>>>>>>>>>>>>>>>>>>>>>>>>>>>>>>>>>>>>>>>>>>>>>>>>>>>>>>>>>>>>>>>>>>>>Set ECG Limit>>>>>>>

//>>>>>>>>>>>>>>>>>>>>>>>>>>>>>>>>>>>>>>>>>>>>>>>>>>>>>>>>>>>>>>>>>>>>>>>>>>>>>>>>>>Set PPG Limit>>>>>>>
// # PPG limit
float UpperThreshold = 100  ;
float LowerThreshold = 0  ;
//>>>>>>>>>>>>>>>>>>>>>>>>>>>>>>>>>>>>>>>>>>>>>>>>>>>>>>>>>>>>>>>>>>>>>>>>>>>>>>>>>>Set PPG Limit>>>>>>>

void setup() 
{
 //>>>>>>>>>>>>>>>>>>>>>>>>>>>>>>>>>>>>>>>>>>>>>>>>>>>>>>>>>>>>>>>>>>>>>>>>>>>>>>>>>>Set COM PORT Here>>>>>>>
  boolean portNr = activateSerialPort("tty.usbserial", 38400);  // Search Phrase and speed
  ArduinoPort.bufferUntil(10);
 //>>>>>>>>>>>>>>>>>>>>>>>>>>>>>>>>>>>>>>>>>>>>>>>>>>>>>>>>>>>>>>>>>>>>>>>>>>>>>>>>>>Set COM PORT Here>>>>>>>

 //>>>>>>>>>>>>>>>>>>>>>>>>>>>>>>>>>>>>>>>>>>>>>>>>>>>>>>>>>>>>>>>>>>>>>>>>>>>>>>>>>>Set Screen Here>>>>>>>
  // Screen
  size(800, 300);
  //size(700, 500);
 //>>>>>>>>>>>>>>>>>>>>>>>>>>>>>>>>>>>>>>>>>>>>>>>>>>>>>>>>>>>>>>>>>>>>>>>>>>>>>>>>>>Set Screen Here>>>>>>>

  NumOfScopes=1;
  sp = new Scope[NumOfScopes];
  sp[0]= new Scope(0,50,50,width-100,height-100,4000,-4000,1000,100);
//  sp[0]= new Scope(0,50,10,width-100,height/2-35,1500,-1500,1000,10);
 // sp[1]= new Scope(1,50,height/2+15,width-100,height/2-35,300,-300,1000,10);
 
  myFont = loadFont("Helvetica-Light-15.vlw");
  myFont2 = loadFont("Helvetica-LightOblique-20.vlw");
  myFont3 = loadFont("Helvetica-BoldOblique-72.vlw");
  textFont(myFont,fontsize); 
  
  mySoundFile = new SoundFile(this, "3.wav");

}



boolean activateSerialPort(String partOfPortName, int SerialSpeed) {
  boolean portIsActivated = false;
  int portIndex = -1;
  
  for(int i = 0; i < Serial.list().length; i++) {   // go thru all serial ports
    print(i);    
    
    if(Serial.list()[i].indexOf(partOfPortName) > 0) { // chech if name match
      portIndex = i;
      print("*");
    }
    println("\t" + Serial.list()[i]);
  }
  
  if(portIndex < 0 ) {
    println("Error: No serial port found - " + partOfPortName);
  }else{
    ArduinoPort = new Serial(this, Serial.list()[portIndex], SerialSpeed);
    println("Serial conection: " + Serial.list()[portIndex] + " speed: " + SerialSpeed);  // activate
  }
  return portIsActivated;  
}
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

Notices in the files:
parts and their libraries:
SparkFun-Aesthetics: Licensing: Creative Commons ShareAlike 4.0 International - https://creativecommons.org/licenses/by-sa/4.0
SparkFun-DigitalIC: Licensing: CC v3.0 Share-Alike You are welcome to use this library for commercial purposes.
